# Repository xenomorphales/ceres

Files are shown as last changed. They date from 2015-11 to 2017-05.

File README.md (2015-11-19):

# Cérès

Cérès est le robot secondaire à roues de l'association Xenomorphales. Le but
premier de notre association étant de participer à la coupe de France de
robotique, ce robot respecte les contraintes imposées au robot secondaire, et
notamment, la contrainte de périmètre.

L'ensemble du robot, que ce soit les modèles mécaniques, les schématiques et
les routages électroniques tout comme les codes sources, tout est sous licence
GPLv3. Libre donc à vous tous de donner vie à ce petit robot de vos propres
mains (et gouttes de sueur) et de vous amuser avec ou d'en apprendre plus sur
la robotique. Nous serions ravis que vous nous partagiez vos expériences avec
nos robots.

Vous pouvez retrouver toute notre actualité ou apprendre à nous connaître sur
notre site internet : http://xenomorphales.org/

## Crédits

- [TheFox/GPLv3.md](https://github.com/TheFox/GPLv3.md) (commit c81a2af) :
pour la GPLv3 en Markdown. C'est plus lisible à lire sur GitHub.

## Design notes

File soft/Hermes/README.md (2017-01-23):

# Hermès

Basic Arduino studio code used for the 2016 edition.
It requires the [Teensy 3.0 Hardware Quadrature library](https://forum.pjrc.com/threads/26803-Hardware-Quadrature-Code-for-Teensy-3-x) to function.

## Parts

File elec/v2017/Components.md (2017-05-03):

Component list for v2017 board:
- 20\* Resistor 10kΩ min 0.25W
- 1\* Resistor 18kΩ min 0.25W
- 8\* Resistor 20kΩ min 0.25W
- 1\* Resistor 100kΩ min 0.25W
- 4\* Ceramic capacitor 100nF min 10V
- 1\* Ceramic capacitor 1µF min 10V
- 12\* Ceramic capacitor 10µF min 15V
- 2\* Leaded electrolytic capacitor 470µF min 15V
- 2\* Female XT60 connector
- 1\* Male XT60 connector
- 5\* Male 5264 3P connector
- 2\* Vertical male connector 2.54mm 2 pins (for pull and TTL-Linker RX/TX)
- 5\* Vertical male connector 2.54mm 3 pins (for extra UART and GP2s)
- 4\* Vertical male connector 2.54mm 4 pins (for ultrasonic sensors)
- 2\* Vertical male connector 2.54mm 2x4 pins (for motor driver and gyro)
- 1\* Vertical male connector 2.54mm 2x15 pins (for embedded card)
- 2\* Vertical socket header 2.54mm 6 pins (for the level shifter, unless you want to solder it directly onto the board)

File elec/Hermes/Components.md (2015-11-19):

Component list for Hermes:
- 4\* [Resistor CMS1206 22Ω 0.25W](http://www.mouser.fr/ProductDetail/Vishay-Dale/CRCW120622R0FKEA/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)
- 5\* [Resistor CMS1206 82Ω 0.25W](http://www.mouser.fr/ProductDetail/Vishay-Dale/CRCW120682R0FKEA/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)
- 19\* [Resistor CMS1206 10kΩ 0.25W](http://www.mouser.fr/ProductDetail/Vishay-Dale/CRCW120610K0FKEA/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)
- 5\* [Resistor CMS1206 18kΩ 0.25W](http://www.mouser.fr/ProductDetail/Vishay-Dale/CRCW120618K0FKEA/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)
- 4\* [Resistor CMS1206 20kΩ 0.25W](http://www.mouser.fr/ProductDetail/Vishay-Dale/CRCW120620K0FKEA/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)
- 5\* [Resistor CMS1206 100kΩ 0.25W](http://www.mouser.fr/ProductDetail/Vishay-Dale/CRCW1206100KFKEA/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)
- 2\* [Ceramic capacitor CMS0603 1nF 50V](http://www.mouser.fr/ProductDetail/Taiyo-Yuden/HMK107B7102KA-T/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)
- 4\* [Ceramic capacitor CMS0603 10nF 50V](http://www.mouser.fr/ProductDetail/Taiyo-Yuden/HMK107B7103KA-T/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)
- 8\* [Ceramic capacitor CMS0603 100nF 25V](http://www.mouser.fr/ProductDetail/Taiyo-Yuden/UMK107B7104KA-T/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)
- 5\* [Ceramic capacitor CMS0603 1µF 25V](http://www.mouser.fr/ProductDetail/Taiyo-Yuden/TMK107B7105KA-T/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)
- 6\* [Ceramic capacitor CMS1210 10µF 25V](http://www.mouser.fr/ProductDetail/Taiyo-Yuden/TMK325B7106KN-TR/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)
- 2\* [Leaded electrolytic capacitor 330µF 35V](http://www.mouser.fr/ProductDetail/Nichicon/UVZ1V331MPD/?qs=sGAEpiMZZMtZ1n0r9vR22cbP6Wf%2fHrkhX5OqxJCqtTQ%3d)
- 5\* [Green LED CMS1206](http://www.mouser.fr/ProductDetail/Kingbright/AP3216CGCK/?qs=VdjlWU%2fzoOG1eeDl%2fnjAXA%3d%3d)
- 2\* [Texas Instruments LMD18201](http://www.mouser.fr/Search/ProductDetail.aspx?qs=7lkVKPoqpbYdwidBC23sGA%3d%3d)
- 10\* [Fuse 5mm x 20mm 6A 125V fast-acting](http://www.mouser.fr/ProductDetail/Bussmann-Eaton/BK-GMA-6-R/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) (10 so you have some in advance)
- 1\* [Fuse holder 6.3A 250V](http://www.mouser.fr/ProductDetail/Littelfuse/64600001003/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)
- 7\* [Vertical male connector 2.54mm 2 pins](http://www.mouser.fr/Search/ProductDetail.aspx?qs=hSmm4fxMIuPWb6osY0uomA%3d%3d)
- 7\* [Vertical female connector 2.54mm 2 pins](http://www.mouser.fr/Search/ProductDetail.aspx?qs=mrPiglD9aYKHxZkM06vJ3A%3d%3d)
- 8\* [Vertical male connector 2.54mm 3 pins](http://www.mouser.fr/ProductDetail/Molex/22-27-2031/?qs=sGAEpiMZZMs%252bGHln7q6pm%252bS0pk2Wo0XxndcUoWleoGk%3d)
- 8\* [Vertical female connector 2.54mm 3 pins](http://www.mouser.fr/ProductDetail/Molex/22-01-2035/?qs=%2fha2pyFadujIEQkzoGlzi6OdgxxLl5ZwtIU0IZrEPkY%3d)
- 2\* [Vertical male connector 2.54mm 4 pins](http://www.mouser.fr/ProductDetail/Molex/22-27-2041/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)
- 2\* [Vertical female connector 2.54mm 4 pins](http://www.mouser.fr/Search/ProductDetail.aspx?qs=mrPiglD9aYK6DF%252b0szbDVw%3d%3d)
- 46\* [Female connector contact](http://www.mouser.fr/Search/ProductDetail.aspx?qs=BLN8Q0P37WapYBZgTV5Zeg%3d%3d)
- 2\* [Teensy socket header](http://www.mouser.fr/ProductDetail/3M/929974-01-14-RK/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) (not necessary if you want to solder the Teensy directly on the board)
- 1\* [Teensy 3.1/3.2 with header pins](https://www.pjrc.com/store/teensy32_pins.html)
- 1\* [XT60 connectors pack (5 pairs)](http://www.hobbyking.com/hobbyking/store/__9572__Nylon_XT60_Connectors_Male_Female_5_pairs_GENUINE.html)

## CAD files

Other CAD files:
meca/v2015/axe.ipt
meca/v2015/axe_roue_moteur.ipt
meca/v2015/base.ipt
meca/v2015/encoder_wheel.ipt
meca/v2015/encoder_wheel_support.ipt
meca/v2015/mat.ipt
meca/v2015/motor_support.ipt
meca/v2015/support_batteries.ipt
meca/v2015/support_discovery.ipt
meca/v2015/support_puissance.ipt
meca/v2015/wheel.ipt
meca/v2015/wheel_adapter.ipt
meca/v2016/base.ipt
meca/v2016/battery_base.ipt
meca/v2016/encoder.iam
meca/v2016/encoder_block.iam
meca/v2016/encoder_support.ipt
meca/v2016/gp2_block.iam
meca/v2016/middle_base.ipt
meca/v2016/motor.iam
meca/v2016/odometer_base.ipt
meca/v2016/odometer_block.iam
meca/v2016/robot_base.iam
meca/v2016/rolling_base_board.ipt
meca/v2016/tendeur.ipt
meca/v2016/tendeur_base.ipt
meca/v2016/tendeur_base_low.ipt
meca/v2016/tendeur_base_up.ipt
meca/v2016/tendeur_block.iam
meca/v2016/tendeur_complet.iam
meca/v2016/tendeur_roue.ipt
meca/v2016/top_base.ipt
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

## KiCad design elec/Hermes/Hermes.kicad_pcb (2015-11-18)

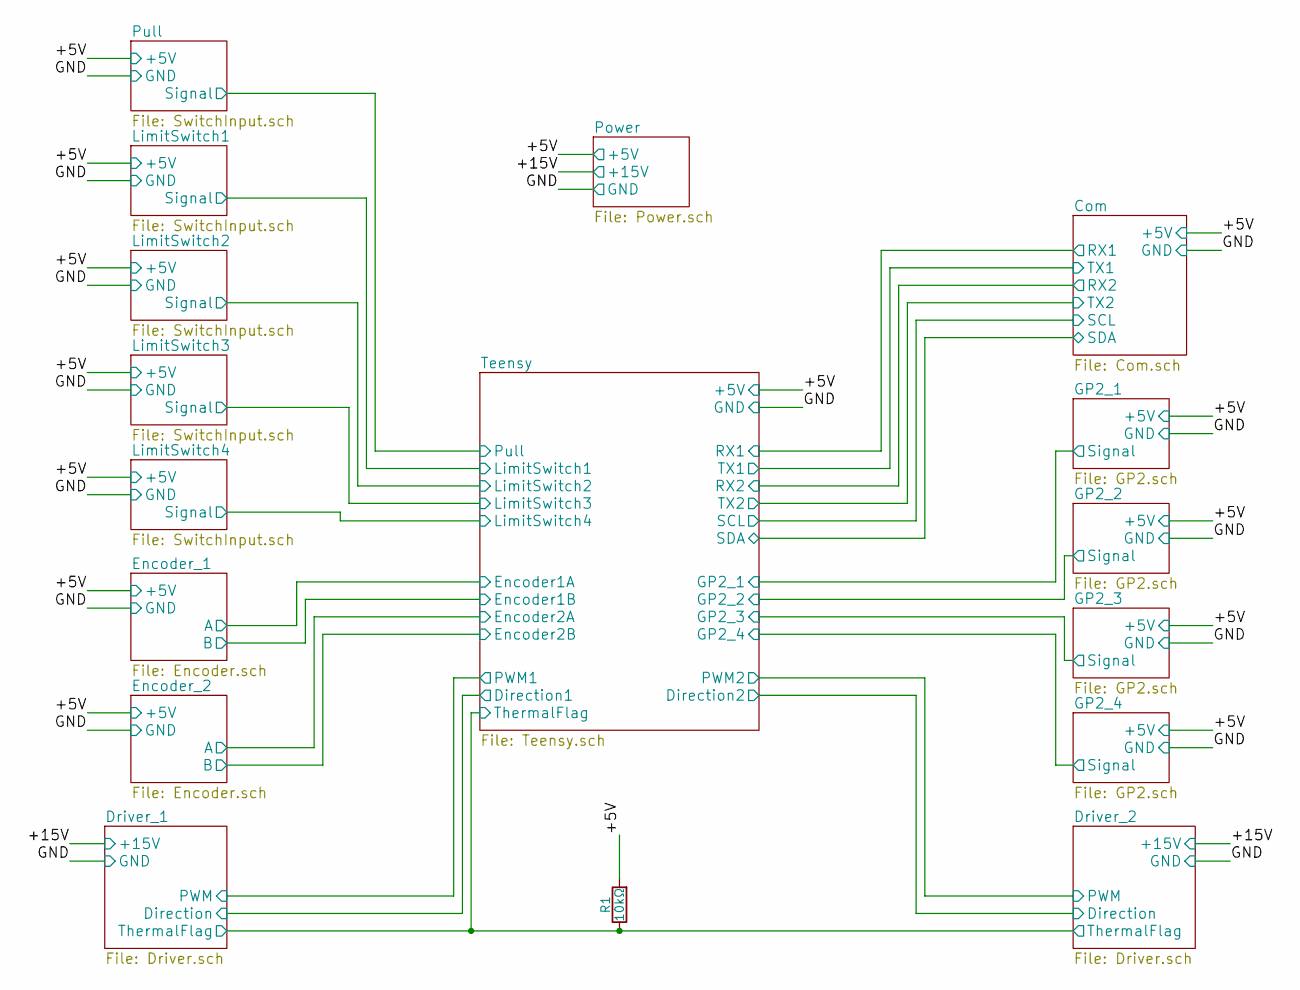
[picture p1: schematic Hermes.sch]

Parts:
R1: 10kΩ; R_CMS1206

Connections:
/Com/+5V: R1.2; also elsewhere on the board
/Driver_1/ThermalFlag: R1.1; also elsewhere on the board

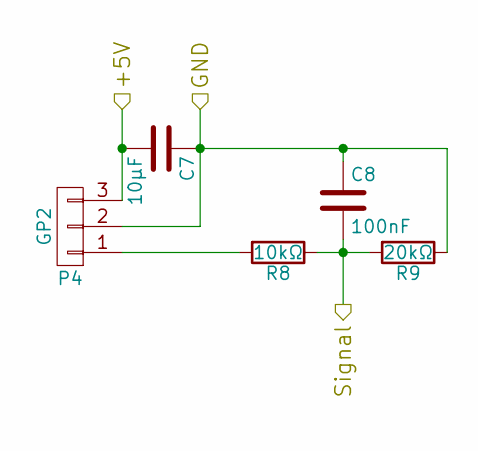
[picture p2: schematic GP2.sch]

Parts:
C1: 10µF; C_CMS1210
C2: 100nF; C_CMS0603
P1: GP2; Conn_01x03
R2: 10kΩ; R_CMS1206
R3: 20kΩ; R_CMS1206

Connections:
/Com/+5V: C1.2, P1.3; also elsewhere on the board
/Com/GND: C1.1, C2.1, P1.2, R3.1; also elsewhere on the board
/Teensy/GP2_1: C2.2, R2.1, R3.2; also elsewhere on the board
unnamed: P1.1, R2.2

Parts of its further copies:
C3, C5, C7: 10µF; C_CMS1210
C4, C6, C8: 100nF; C_CMS0603
P2, P3, P4: GP2; Conn_01x03
R4, R6, R8: 10kΩ; R_CMS1206
R5, R7, R9: 20kΩ; R_CMS1206

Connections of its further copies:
/Com/+5V: C3.2, C5.2, C7.2, P2.3, P3.3, P4.3; also elsewhere on the board
/Com/GND: C3.1, C4.1, C5.1, C6.1, C7.1, C8.1, P2.2, P3.2, P4.2, R5.1, R7.1, R9.1; also elsewhere on the board
/Teensy/GP2_2: C4.2, R4.1, R5.2; also elsewhere on the board
/Teensy/GP2_3: C6.2, R6.1, R7.2; also elsewhere on the board
/Teensy/GP2_4: C8.2, R8.1, R9.2; also elsewhere on the board
unnamed: P2.1, R4.2
unnamed: P3.1, R6.2
unnamed: P4.1, R8.2

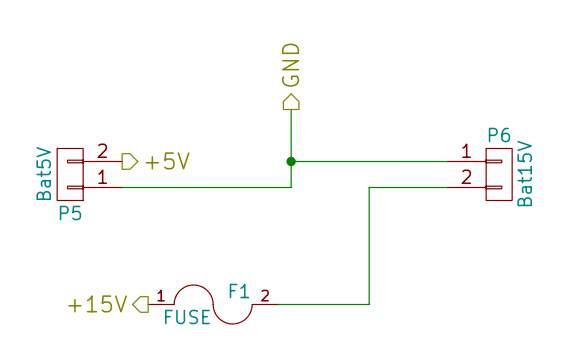
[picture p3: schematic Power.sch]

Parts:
F1: FUSE; Fuse
P5: Bat5V; Conn_01x02
P6: Bat15V; Power_Conn_01x02

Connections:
/Com/+5V: P5.2; also elsewhere on the board
/Com/GND: P5.1, P6.1; also elsewhere on the board
/Driver_1/+15V: F1.1; also elsewhere on the board
unnamed: F1.2, P6.2

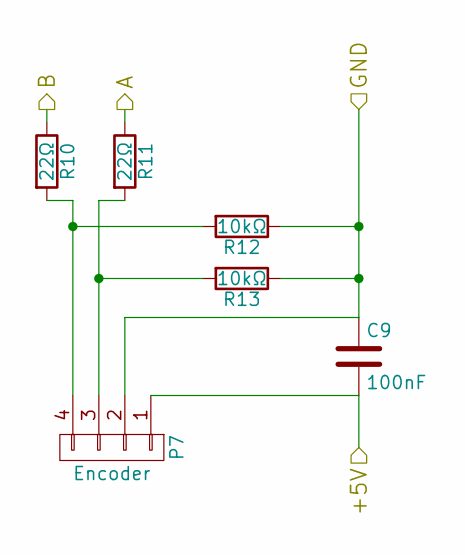
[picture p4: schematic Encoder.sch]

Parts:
C9: 100nF; C_CMS0603
P7: Encoder; Conn_01x04
R10, R11: 22Ω; R_CMS1206
R12, R13: 10kΩ; R_CMS1206

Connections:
/Com/+5V: C9.2, P7.1; also elsewhere on the board
/Com/GND: C9.1, P7.2, R12.1, R13.1; also elsewhere on the board
/Encoder_1/A: R11.1; also elsewhere on the board
/Encoder_1/B: R10.1; also elsewhere on the board
unnamed: P7.3, R11.2, R13.2
unnamed: P7.4, R10.2, R12.2

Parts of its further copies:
C10: 100nF; C_CMS0603
P8: Encoder; Conn_01x04
R14, R15: 22Ω; R_CMS1206
R16, R17: 10kΩ; R_CMS1206

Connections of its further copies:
/Com/+5V: C10.2, P8.1; also elsewhere on the board
/Com/GND: C10.1, P8.2, R16.1, R17.1; also elsewhere on the board
/Encoder_2/A: R15.1; also elsewhere on the board
/Encoder_2/B: R14.1; also elsewhere on the board
unnamed: P8.3, R15.2, R17.2
unnamed: P8.4, R14.2, R16.2

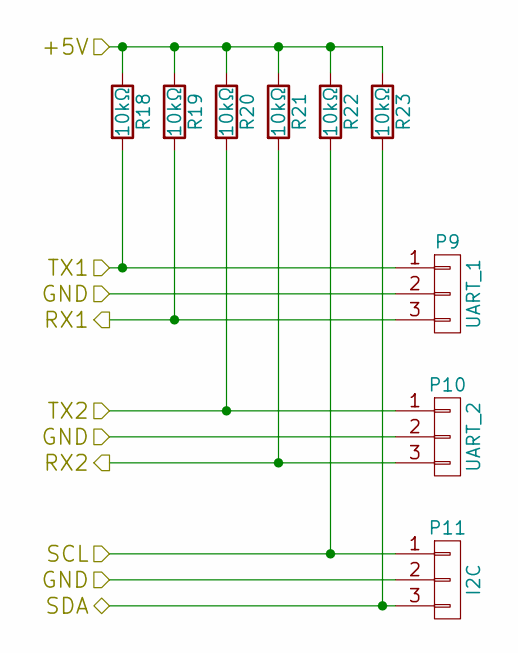
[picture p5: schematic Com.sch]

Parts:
P9: UART_1; Conn_01x03
P10: UART_2; Conn_01x03
P11: I2C; Conn_01x03
R18, R19, R20, R21, R22, R23: 10kΩ; R_CMS1206

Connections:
/Com/+5V: R18.1, R19.1, R20.1, R21.1, R22.1, R23.1; also elsewhere on the board
/Com/GND: P9.2, P10.2, P11.2; also elsewhere on the board
/Com/RX1: P9.3, R19.2; also elsewhere on the board
/Com/RX2: P10.3, R21.2; also elsewhere on the board
/Com/SCL: P11.1, R22.2; also elsewhere on the board
/Com/SDA: P11.3, R23.2; also elsewhere on the board
/Com/TX1: P9.1, R18.2; also elsewhere on the board
/Com/TX2: P10.1, R20.2; also elsewhere on the board

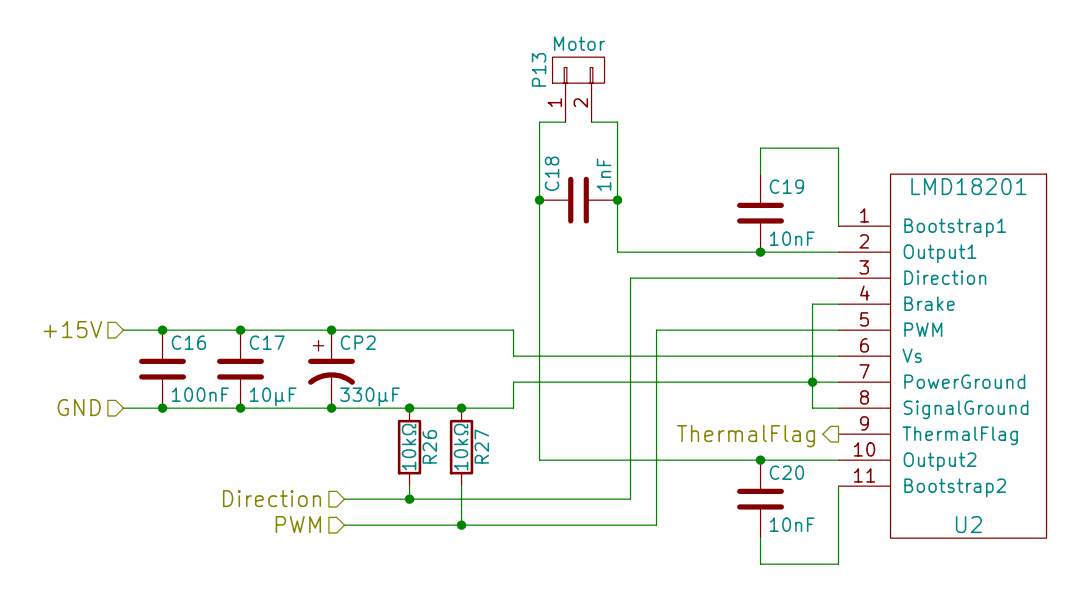
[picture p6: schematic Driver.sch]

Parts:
C11: 100nF; C_CMS0603
C12: 10µF; C_CMS1210
C13: 1nF; C_CMS0603
C14, C15: 10nF; C_CMS0603
CP1: 330µF; C_Radial
P12: Motor; Power_Conn_01x02
R24, R25: 10kΩ; R_CMS1206
U1: LMD18201

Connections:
/Com/GND: C11.2, C12.2, CP1.2, R24.1, R25.1, U1.4 (Brake), U1.7 (PowerGround), U1.8 (SignalGround); also elsewhere on the board
/Driver_1/+15V: C11.1, C12.1, CP1.1, U1.6 (Vs); also elsewhere on the board
/Driver_1/Direction: R24.2, U1.3 (Direction); also elsewhere on the board
/Driver_1/PWM: R25.2, U1.5 (PWM); also elsewhere on the board
/Driver_1/ThermalFlag: U1.9 (ThermalFlag); also elsewhere on the board
unnamed: C13.1, C15.1, P12.1, U1.10 (Output2)
unnamed: C13.2, C14.2, P12.2, U1.2 (Output1)
unnamed: C14.1, U1.1 (Bootstrap1)
unnamed: C15.2, U1.11 (Bootstrap2)

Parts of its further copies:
C16: 100nF; C_CMS0603
C17: 10µF; C_CMS1210
C18: 1nF; C_CMS0603
C19, C20: 10nF; C_CMS0603
CP2: 330µF; C_Radial
P13: Motor; Power_Conn_01x02
R26, R27: 10kΩ; R_CMS1206
U2: LMD18201

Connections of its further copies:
/Com/GND: C16.2, C17.2, CP2.2, R26.1, R27.1, U2.4 (Brake), U2.7 (PowerGround), U2.8 (SignalGround); also elsewhere on the board
/Driver_1/+15V: C16.1, C17.1, CP2.1, U2.6 (Vs); also elsewhere on the board
/Driver_1/ThermalFlag: U2.9 (ThermalFlag); also elsewhere on the board
/Driver_2/Direction: R26.2, U2.3 (Direction); also elsewhere on the board
/Driver_2/PWM: R27.2, U2.5 (PWM); also elsewhere on the board
unnamed: C18.1, C20.1, P13.1, U2.10 (Output2)
unnamed: C18.2, C19.2, P13.2, U2.2 (Output1)
unnamed: C19.1, U2.1 (Bootstrap1)
unnamed: C20.2, U2.11 (Bootstrap2)

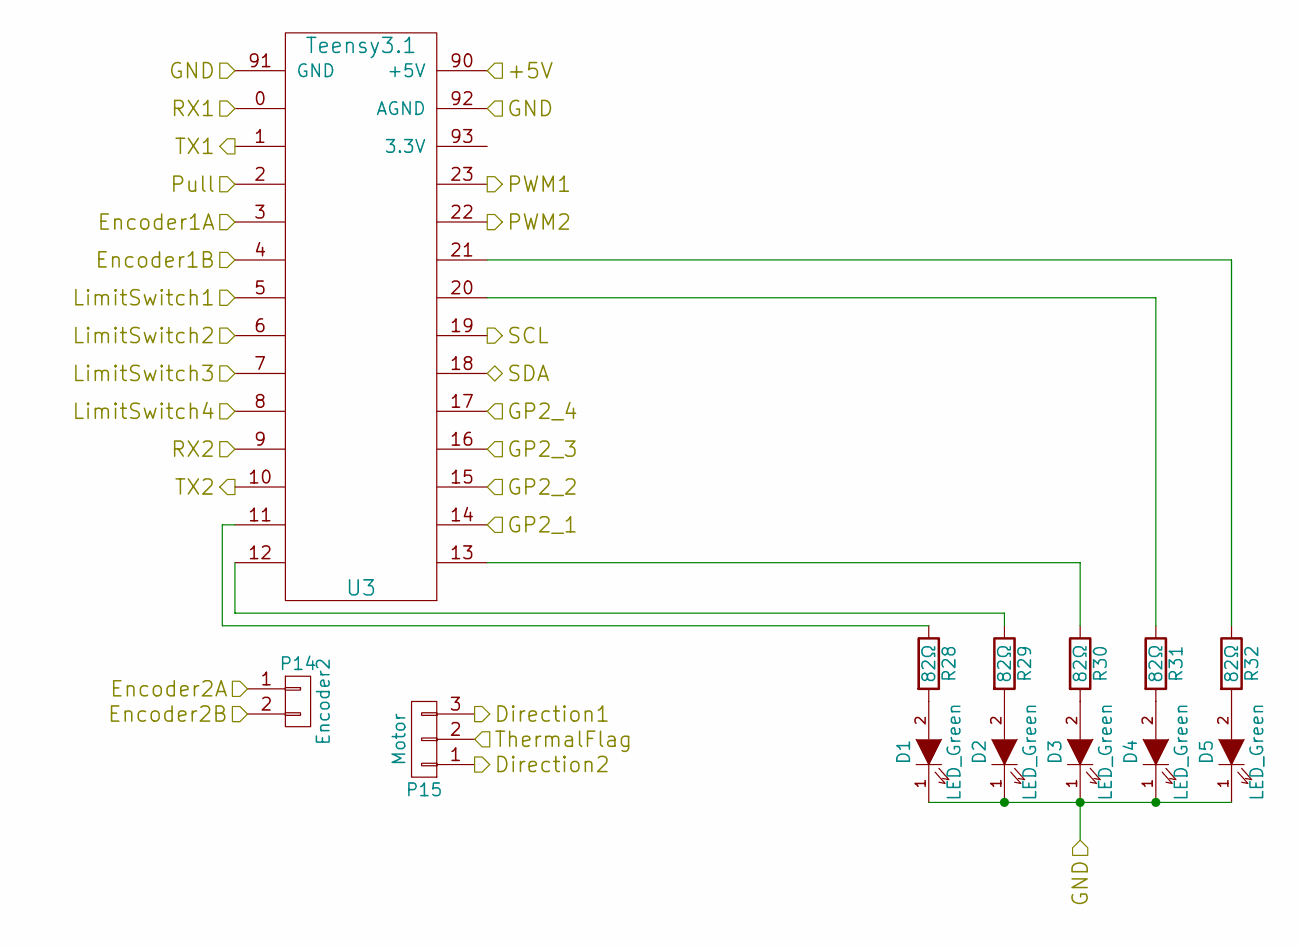
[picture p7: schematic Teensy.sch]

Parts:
D1, D2, D3, D4, D5: LED_Green; LED_Green_CMS
P14: Encoder2; Conn_01x02
P15: Motor; Conn_01x03
R28, R29, R30, R31, R32: 82Ω; R_CMS1206
U3: Teensy3.1

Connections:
/Com/+5V: U3.90 (+5V); also elsewhere on the board
/Com/GND: D1.1 (K), D2.1 (K), D3.1 (K), D4.1 (K), D5.1 (K), U3.91 (GND), U3.92 (AGND); also elsewhere on the board
/Com/RX1: U3.0; also elsewhere on the board
/Com/RX2: U3.9; also elsewhere on the board
/Com/SCL: U3.19; also elsewhere on the board
/Com/SDA: U3.18; also elsewhere on the board
/Com/TX1: U3.1; also elsewhere on the board
/Com/TX2: U3.10; also elsewhere on the board
/Driver_1/Direction: P15.3; also elsewhere on the board
/Driver_1/PWM: U3.23; also elsewhere on the board
/Driver_1/ThermalFlag: P15.2; also elsewhere on the board
/Driver_2/Direction: P15.1; also elsewhere on the board
/Driver_2/PWM: U3.22; also elsewhere on the board
/Encoder_1/A: U3.3; also elsewhere on the board
/Encoder_1/B: U3.4; also elsewhere on the board
/Encoder_2/A: P14.1; also elsewhere on the board
/Encoder_2/B: P14.2; also elsewhere on the board
/Teensy/GP2_1: U3.14; also elsewhere on the board
/Teensy/GP2_2: U3.15; also elsewhere on the board
/Teensy/GP2_3: U3.16; also elsewhere on the board
/Teensy/GP2_4: U3.17; also elsewhere on the board
/Teensy/LimitSwitch1: U3.5; also elsewhere on the board
/Teensy/LimitSwitch2: U3.6; also elsewhere on the board
/Teensy/LimitSwitch3: U3.7; also elsewhere on the board
/Teensy/LimitSwitch4: U3.8; also elsewhere on the board
/Teensy/Pull: U3.2; also elsewhere on the board
unnamed: D1.2 (A), R28.2
unnamed: D2.2 (A), R29.2
unnamed: D3.2 (A), R30.2
unnamed: D4.2 (A), R31.2
unnamed: D5.2 (A), R32.2
unnamed: R28.1, U3.11
unnamed: R29.1, U3.12
unnamed: R30.1, U3.13
unnamed: R31.1, U3.20
unnamed: R32.1, U3.21

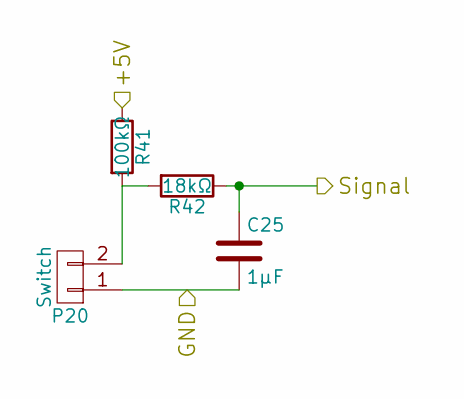
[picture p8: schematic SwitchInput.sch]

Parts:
C21: 1µF; C_CMS0603
P16: Switch; Conn_01x02
R33: 100kΩ; R_CMS1206
R34: 18kΩ; R_CMS1206

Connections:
/Com/+5V: R33.1; also elsewhere on the board
/Com/GND: C21.2, P16.1; also elsewhere on the board
/Teensy/Pull: C21.1, R34.1; also elsewhere on the board
unnamed: P16.2, R33.2, R34.2

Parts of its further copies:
C22, C23, C24, C25: 1µF; C_CMS0603
P17, P18, P19, P20: Switch; Conn_01x02
R35, R37, R39, R41: 100kΩ; R_CMS1206
R36, R38, R40, R42: 18kΩ; R_CMS1206

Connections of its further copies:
/Com/+5V: R35.1, R37.1, R39.1, R41.1; also elsewhere on the board
/Com/GND: C22.2, C23.2, C24.2, C25.2, P17.1, P18.1, P19.1, P20.1; also elsewhere on the board
/Teensy/LimitSwitch1: C22.1, R36.1; also elsewhere on the board
/Teensy/LimitSwitch2: C23.1, R38.1; also elsewhere on the board
/Teensy/LimitSwitch3: C24.1, R40.1; also elsewhere on the board
/Teensy/LimitSwitch4: C25.1, R42.1; also elsewhere on the board
unnamed: P17.2, R35.2, R36.2
unnamed: P18.2, R37.2, R38.2
unnamed: P19.2, R39.2, R40.2
unnamed: P20.2, R41.2, R42.2

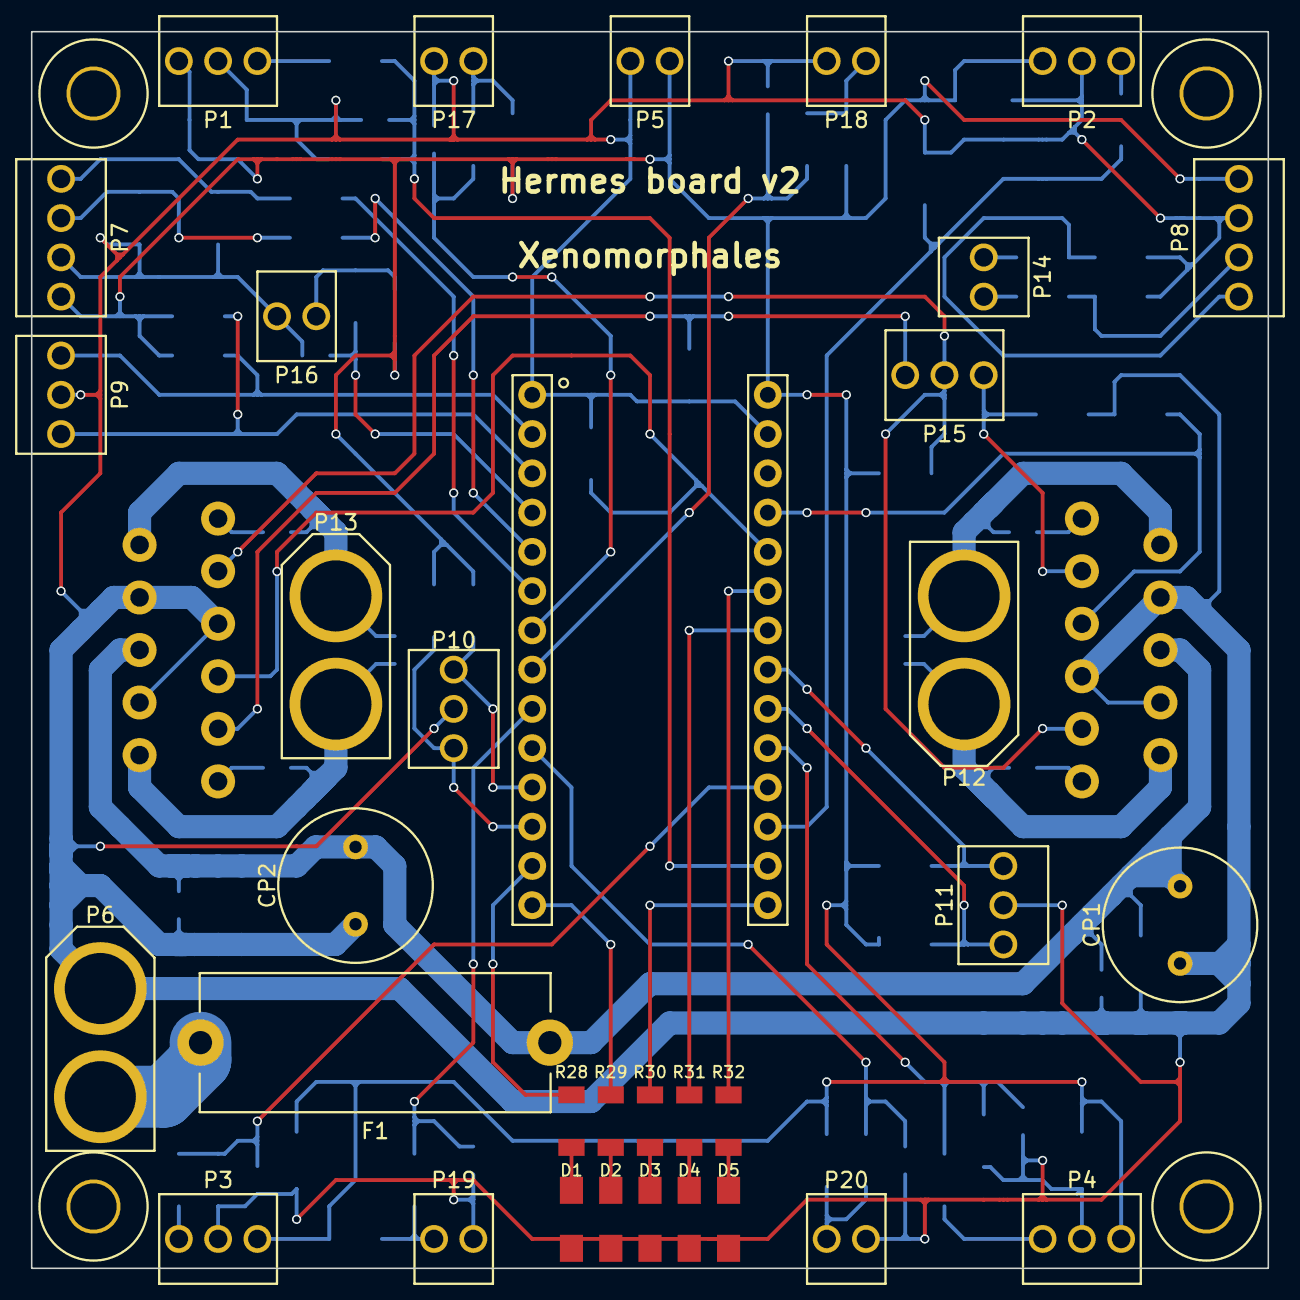
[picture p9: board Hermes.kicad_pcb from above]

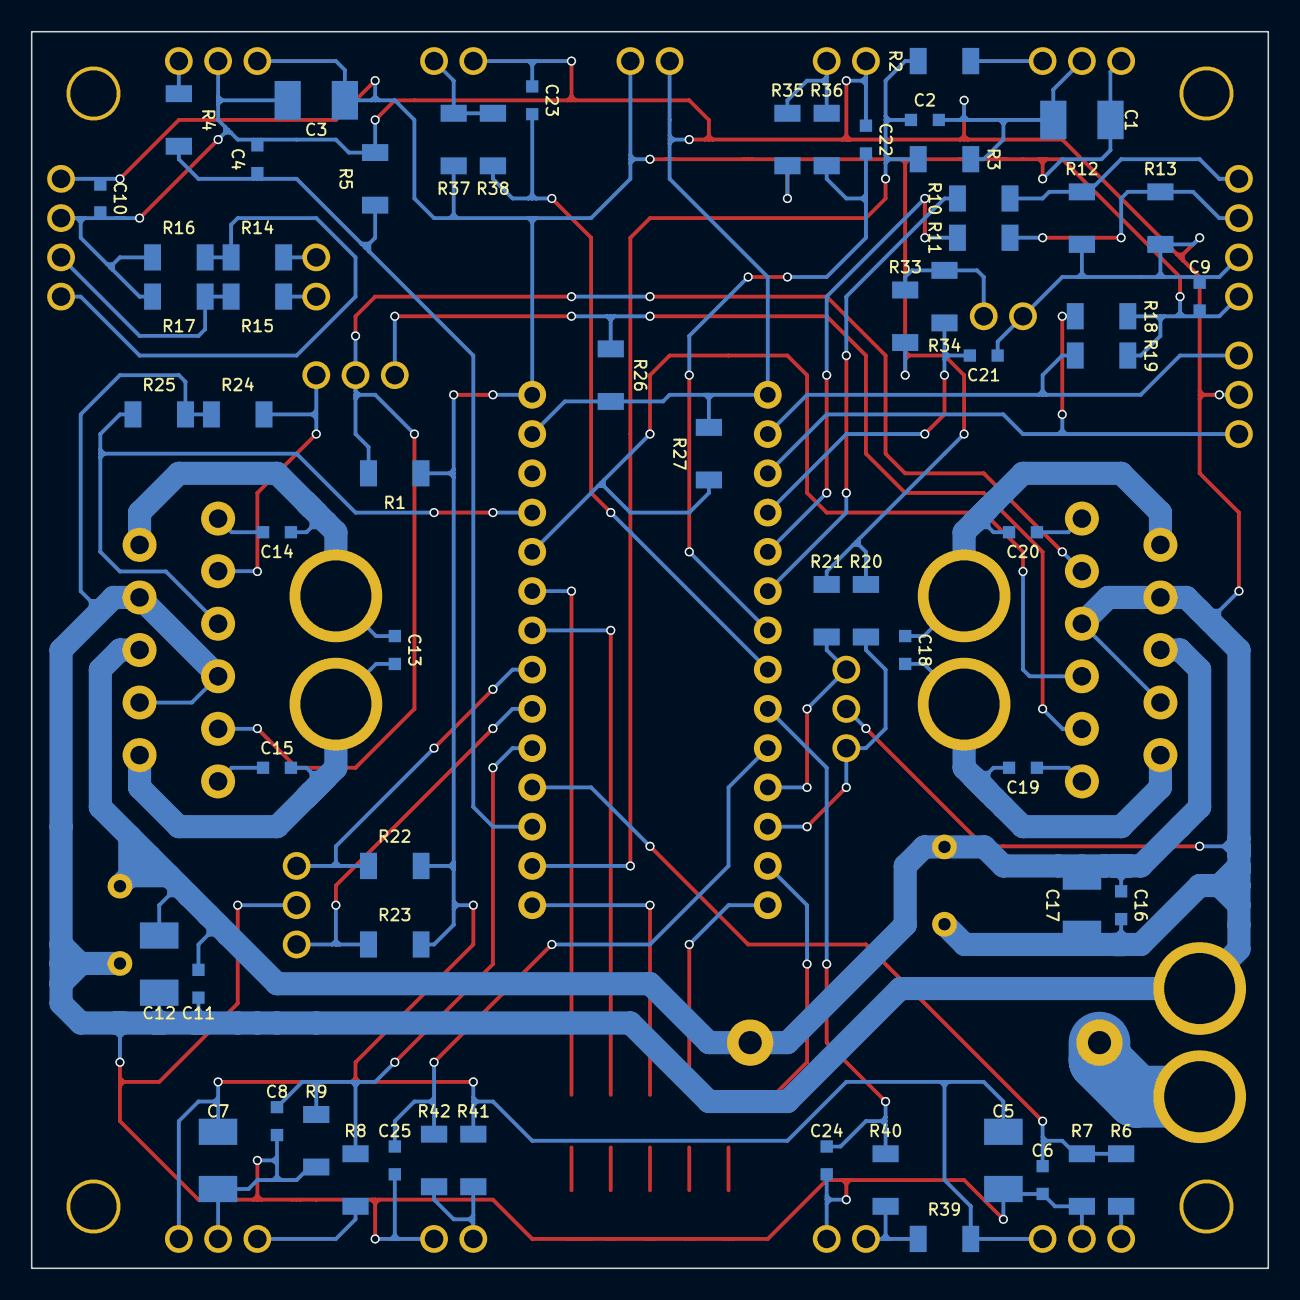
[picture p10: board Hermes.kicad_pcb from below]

Board: 2 copper layers, 80.0 x 80.0 mm, 98 parts (62 on the bottom side), 59 nets.

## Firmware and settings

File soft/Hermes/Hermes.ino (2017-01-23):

#include "QuadDecode_def.h"

#define NB_LEDS 5
const int leds[] = { 11, 12, 13, 20, 21 };

#define NB_BUTTONS 4
const int buttons[] = { 5, 6, 7 , 8 };

const int startPull = 2;

#define NB_GP2S 4
const int gp2s[] = { 0, 1, 2, 3 };
#define GP2_BLOCK_AT   1000 /*432*/ /*288*/
#define GP2_UNBLOCK_AT 1000 /*324*/ /*216*/

#define NB_MOTORS 2
const int motorPWMs[] = { 22, 23 };
const int motorDirs[] = { 26, 31 };

QuadDecode<1> encoder1;  // Template using FTM1
QuadDecode<2> encoder2;  // Template using FTM2

#define SPEED 125

void display(int n) {
  for(int i = 0; i <= NB_LEDS; ++i)
    digitalWrite(leds[i], ((1<<i) & n) ? HIGH : LOW);
}

static long long lastE[2] = { 0, 0 };
static long long curE[2] = { 0, 0 };

void updateEnc() {
  lastE[0] = curE[0];
  lastE[1] = curE[1];

  curE[0] = -encoder2.calcPosn();
  curE[1] = encoder1.calcPosn();
}

static long long lastErr[2] = { 0, 0 };
static float pidSpeeds[2][3] = {
  //    P     I     D
  {   0.5,   0.,  0.5 }, // Droit
  {   0.5,   0.,  0.5 }, // Gauche
};

void updateMotor(int m, int speed) {
  long long actualSpeed = curE[m] - lastE[m];
  long long err = speed - actualSpeed;
  
  long long P = pidSpeeds[m][0] * err;
  long long I = 0;
  long long D = pidSpeeds[m][2] * (err - lastErr[m]);

  long long cmd = P + I + D;

  if(m == 0) cmd = -cmd;
  
  analogWrite(motorPWMs[m], (abs(cmd) > 255) ? 255 : abs(cmd));
  digitalWrite(motorDirs[m], (cmd >= 0) ? HIGH : LOW);
  
  lastErr[m] = err;
}

long long lastErrAngle = 0;
static float pidAngle[3] = {
  //    P     I     D
      0.5,   0.,  0.5,
};

long long lastDistance = 0;
long long lastErrSpeed = 0;
static float pidSpeed[3] = {
  //    P     I     D
      0.5,   0.,  0.5,
};

void updateAngleSpeed(int angle, int speed) {
  long long actualAngle = (curE[1] - curE[0]) / 2;
  long long actualDistance = (curE[1] + curE[0]) / 2;

  long long errAngle = angle - actualAngle;

  long long PAngle = pidAngle[0] * errAngle;
  long long IAngle = 0;
  long long DAngle = pidAngle[2] * (errAngle - lastErrAngle);

  long long actualSpeed = lastDistance - actualDistance;

  long long errSpeed = speed - actualSpeed;

  long long PSpeed = pidSpeed[0] * errSpeed;
  long long ISpeed = 0;
  long long DSpeed = pidSpeed[2] * (errSpeed - lastErrSpeed);

  updateMotor(1, PSpeed + ISpeed + DSpeed + PAngle + IAngle + DAngle);
  updateMotor(0, PSpeed + ISpeed + DSpeed - PAngle - IAngle - DAngle);

  lastErrAngle = errAngle;
  lastDistance = actualDistance;
  lastErrSpeed = errSpeed;
}

void updateMotors(int speed) {
  updateMotor(0, speed);
  updateMotor(1, speed);
}

void setup() {
  // put your setup code here, to run once:
  delay(1000);

  for(int i = 0; i < NB_LEDS; ++i)
    pinMode(leds[i], OUTPUT);

  display(0x1F);

  for(int i = 0; i < NB_BUTTONS; ++i)
    pinMode(buttons[i], INPUT);

  pinMode(startPull, INPUT);

  for(int i = 0; i < NB_GP2S; ++i)
    pinMode(gp2s[i], INPUT);

  for(int i = 0; i < NB_MOTORS; ++i) {
    pinMode(motorPWMs[i], OUTPUT);
    pinMode(motorDirs[i], OUTPUT);
  }

  updateMotors(0);

  encoder1.setup();
  encoder2.setup();

  delay(1000);
}

void loop() {
  // put your main code here, to run repeatedly:
  static int time = 0;
  static int step = 0;
  
  display(step);

  if(time >= 85000) {
    display(0x1F);
    while(1) {
      analogWrite(motorPWMs[0], 0);
      analogWrite(motorPWMs[1], 0);
    }
  }

  if(step == 0) {
    while(digitalRead(buttons[0]) == HIGH);
    step = 1;
  }
  else if(step == 1) {
    //while(digitalRead(buttons[1]) == HIGH);
    while(digitalRead(startPull) == LOW);
    time = 0;
    step = 2;
    encoder1.start();
    encoder2.start();
  }
  else if(step == 2) {
    int speed = SPEED;
    long long dist;
    static bool lastBlocked = false;
    int gp2Sum = 0;
    
    updateEnc();
    dist = curE[0] + curE[1];

    for(int i = 0; i < 2 && speed != 0; ++i)
      if(lastBlocked) {
        if(analogRead(gp2s[i]) <= GP2_UNBLOCK_AT)
          ++gp2Sum;
      }
      else {
        if(analogRead(gp2s[i]) >= GP2_BLOCK_AT)
          ++gp2Sum;
      }

    if(lastBlocked && gp2Sum < 2)
      speed = 0;
    else if(lastBlocked && gp2Sum == 2)
      lastBlocked = false;
    else if(!lastBlocked && gp2Sum > 0) {
      lastBlocked = true;
      speed = 0;
    }

    display(step | ((lastBlocked) ? 0b11000 : 0));
    
    //updateMotors(speed);
    updateAngleSpeed(0, speed);

    if(dist >= 1024*34)
      step = 3;
  }
  else if(step == 3) {
    updateEnc();
    updateMotors(0);
    if(time >= 80000)
      step = 4;
  }
  /*else if(step == 4) {
    // Toupie
    updateEnc();
    updateMotor(0, SPEED);
    updateMotor(1, -SPEED);
  }*/
  else {
    updateEnc();
    updateMotors(0);
  }
  
  delay(10);
  time += 10;
}

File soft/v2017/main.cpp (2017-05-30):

#include <stdio.h>
#include <math.h>
#include <string.h>

#include <shell.h>

#include "task.h"

#include "strategy.hpp"

extern int cmd_read(int argc, char** argv);
extern int cmd_write(int argc, char** argv);
extern int cmd_ls(int argc, char** argv);

extern int cmd_service(int argc, char** argv);

extern int cmd_feetech(int argc, char **argv);
extern int cmd_dxl(int argc, char **argv);

extern int cmd_test_all(int, char**);
extern int cmd_test_speed(int argc, char** argv);
extern int cmd_test_funny(int argc, char** argv);
extern int cmd_test_grip(int argc, char** argv);
extern int cmd_test_arm(int argc, char** argv);
extern int cmd_test_side(int argc, char** argv);

static const shell_command_t shell_commands[] = {
  { "read", "", cmd_read },
  { "write", "", cmd_write },
  { "ls", "", cmd_ls },

  { "service", "Service management", cmd_service },

  { "feetech", "Feetech management", cmd_feetech },
  { "dxl", "Dynamixel management", cmd_dxl },

  { "init_all", "Init all services", cmd_test_all},
  { "test", "Test speed*time", cmd_test_speed},
  { "funny", "Test funny action", cmd_test_funny},
  { "grip", "Test grip", cmd_test_grip},
  { "arm", "Test grip", cmd_test_arm},
  { "side", "Choose side", cmd_test_side},

  { NULL, NULL, NULL }
};

int main(void) {
  task_init();

  puts("Starting the shell");

  Strategy::instance().start();
  char line_buf[SHELL_DEFAULT_BUFSIZE];
  shell_run(shell_commands, line_buf, SHELL_DEFAULT_BUFSIZE);

  return 0;
}

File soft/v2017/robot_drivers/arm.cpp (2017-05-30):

#include "arm.hpp"

#include "servo.hpp"

#include <thread.h>
#include <xtimer.h>

#include <stdint.h>

#define ARM_SERVO_NUMOF (5)

#define SERVO_DELTA (10)

typedef enum {
  RETRACTED       = 0,
  DEPLOYED_MIDDLE = 1,
  DEPLOYED_DOWN   = 2,
} pose_t;

typedef enum {
  STATE_OFF,
  STATE_INIT,
  STATE_RETRACTED,
  STATE_DEPLOYED,
  STATE_MOVING_RETRACT_1,
  STATE_MOVING_RETRACT_2,
  STATE_MOVING_DEPLOY_1,
  STATE_MOVING_DEPLOY_2,

  STATE_ERROR
} state_t;

typedef enum {
  EVENT_INIT,
  EVENT_DEPLOY,
  EVENT_RETRACT,
  EVENT_DONE,

  EVENT_EMPTY
} event_t;

static uint8_t _left_ids[ARM_SERVO_NUMOF] = {
  10, 11, 12, 13, 14
};

static uint8_t _right_ids[ARM_SERVO_NUMOF] = {
  20, 21, 22, 23, 24
};

static uint16_t _left_poses[3][ARM_SERVO_NUMOF] = {
  {170,  80, 540, 400, 200}, // RETRACTED
  {512, 512, 630, 270, 130}, // DEPLOYED_MIDDLE
  {512, 512, 100, 700, 130}, // DEPLOYED_DOWN
};

static uint16_t _right_poses[3][ARM_SERVO_NUMOF] = {
  {140, 140, 540, 330, 180}, // RETRACTED
  {512, 512, 630, 270, 150}, // DEPLOYED_MIDDLE
  {512, 512, 100, 700, 150}, // DEPLOYED_DOWN
};

static float _left_angles[ARM_SERVO_NUMOF] = { 0,0,0,0,0 };
static float _right_angles[ARM_SERVO_NUMOF] = { 0,0,0,0,0 };

static float _no_angles[ARM_SERVO_NUMOF] = { 0,0,0,0,0 };

static state_t _left_state = STATE_OFF;
static event_t _left_event = EVENT_EMPTY;

static state_t _right_state = STATE_OFF;
static event_t _right_event = EVENT_EMPTY;

static char arm_thread_stack[THREAD_STACKSIZE_MAIN];

void _servo_enable(uint8_t id) {
  feetech_t dev;
  feetech_init(&dev, &ServoBus::instance().stream(), id);
  feetech_write8(&dev, SCS15_TORQUE_ENABLE, 1);
  feetech_write16(&dev, SCS15_GOAL_TIME, 512);
}

void _servo_set_angle(uint8_t id, uint16_t angle) {
  feetech_t dev;
  feetech_init(&dev, &ServoBus::instance().stream(), id);
  feetech_write8(&dev, SCS15_TORQUE_ENABLE, 1);
  feetech_write16(&dev, SCS15_GOAL_TIME, 512);
  feetech_write16(&dev, SCS15_GOAL_POSITION, angle);
}

bool _servo_check_angle(uint8_t id, uint16_t angle) {
  uint16_t res = 0xFFFF;
  feetech_t dev;
  feetech_init(&dev, &ServoBus::instance().stream(), id);
  feetech_read16(&dev, SCS15_PRESENT_POSITION, &res);

  return abs((int)res-(int)angle) < SERVO_DELTA;
}

void _arm_enable(uint8_t ids[ARM_SERVO_NUMOF]) {
  for(size_t i = 0 ; i < ARM_SERVO_NUMOF ; i++) {
    _servo_enable(ids[i]);
  }
}

uint16_t add_angle(uint16_t pose, float angle) {
  const int p = pose;
  const int a = angle * 1024 / 3.1415;

  const int ret = p+a;

  if(ret < 0) return 0;
  if(ret > 1024) return 1024;

  return ret;
}

void _arm_set_pose(uint8_t ids[ARM_SERVO_NUMOF], uint16_t pose[ARM_SERVO_NUMOF], float angle[ARM_SERVO_NUMOF]) {
  for(size_t i = 0 ; i < ARM_SERVO_NUMOF ; i++) {
    _servo_set_angle(ids[i], add_angle(pose[i], angle[i]));
  }
}

bool _arm_check_pose(uint8_t ids[ARM_SERVO_NUMOF], uint16_t pose[ARM_SERVO_NUMOF], float angle[ARM_SERVO_NUMOF]) {
  for(size_t i = 0 ; i < ARM_SERVO_NUMOF ; i++) {
    if(!_servo_check_angle(ids[i], add_angle(pose[i], angle[i]))) {
      return false;
    }
  }
  return true;
}

static inline event_t _update_event(uint8_t ids[ARM_SERVO_NUMOF], uint16_t poses[3][ARM_SERVO_NUMOF], float angle[ARM_SERVO_NUMOF], state_t state) {
  if(state == STATE_OFF) {
  }
  else if(state == STATE_INIT) {
    return EVENT_DONE;
  }
  else if(state == STATE_MOVING_DEPLOY_1) {
    if(_arm_check_pose(ids, poses[DEPLOYED_MIDDLE], _no_angles)) {
      return EVENT_DONE;
    }
  }
  else if(state == STATE_MOVING_DEPLOY_2) {
    if(_arm_check_pose(ids, poses[DEPLOYED_DOWN], angle)) {
      return EVENT_DONE;
    }
  }
  else if(state == STATE_MOVING_RETRACT_1) {
    if(_arm_check_pose(ids, poses[DEPLOYED_MIDDLE], _no_angles)) {
      return EVENT_DONE;
    }
  }
  else if(state == STATE_MOVING_RETRACT_2) {
    if(_arm_check_pose(ids, poses[RETRACTED], _no_angles)) {
      return EVENT_DONE;
    }
  }

  return EVENT_EMPTY;
}

static inline state_t _update_state(uint8_t ids[ARM_SERVO_NUMOF], uint16_t poses[3][ARM_SERVO_NUMOF], float angle[ARM_SERVO_NUMOF], state_t state, event_t event) {
  if(state == STATE_OFF) {
    if(event == EVENT_INIT) {
      _arm_enable(ids);
      return STATE_INIT;
    }
  }
  else if(state == STATE_INIT) {
    if(event == EVENT_DONE) {
      _arm_set_pose(ids, poses[DEPLOYED_MIDDLE], _no_angles);
      return STATE_MOVING_RETRACT_1;
    }
  }
  else if(state == STATE_RETRACTED) {
    if(event == EVENT_DEPLOY) {
      _arm_set_pose(ids, poses[DEPLOYED_MIDDLE], _no_angles);
      return STATE_MOVING_DEPLOY_1;
    }
  }
  else if(state == STATE_DEPLOYED) {
    if(event == EVENT_RETRACT) {
      _arm_set_pose(ids, poses[DEPLOYED_MIDDLE], _no_angles);
      return STATE_MOVING_RETRACT_1;
    }
    if(event == EVENT_DEPLOY) {
      _arm_set_pose(ids, poses[DEPLOYED_DOWN], angle);
      return STATE_DEPLOYED;
    }
  }
  else if(state == STATE_MOVING_DEPLOY_1) {
    if(event == EVENT_DONE) {
      _arm_set_pose(ids, poses[DEPLOYED_DOWN], angle);
      return STATE_MOVING_DEPLOY_2;
    }
  }
  else if(state == STATE_MOVING_DEPLOY_2) {
    if(event == EVENT_DONE) {
      return STATE_DEPLOYED;
    }
  }
  else if(state == STATE_MOVING_RETRACT_1) {
    if(event == EVENT_DONE) {
      _arm_set_pose(ids, poses[RETRACTED], _no_angles);
      return STATE_MOVING_RETRACT_2;
    }
  }
  else if(state == STATE_MOVING_RETRACT_2) {
    if(event == EVENT_DONE) {
      return STATE_RETRACTED;
    }
  }

  return state;
}

static inline Arm::ArmState _arm_state(state_t state) {
  switch(state) {
    case STATE_DEPLOYED:
      return Arm::ARM_DEPLOYED;
    case STATE_RETRACTED:
      return Arm::ARM_RETRACTED;
    case STATE_INIT:
    case STATE_MOVING_DEPLOY_1:
    case STATE_MOVING_DEPLOY_2:
    case STATE_MOVING_RETRACT_1:
    case STATE_MOVING_RETRACT_2:
      return Arm::ARM_MOVING;
    case STATE_OFF:
      return Arm::ARM_DISABLED;
    default:
      return Arm::ARM_ERROR;
  }
  return Arm::ARM_ERROR;
}

static void* _arm_update_thread(void* arg) {
  (void) arg;
  xtimer_ticks32_t last_wakeup = xtimer_now();

  while(1) {
    xtimer_periodic_wakeup(&last_wakeup, 1000000UL/10UL);

    if(Arm::instance().state() == Service::RUN) {
      // LEFT
      if(_left_event == EVENT_EMPTY) {
        _left_event = _update_event(_left_ids, _left_poses, _left_angles, _left_state);
      }

      _left_state = _update_state(_left_ids, _left_poses, _left_angles, _left_state, _left_event);
      _left_event = EVENT_EMPTY;

      // RIGHT
      if(_right_event == EVENT_EMPTY) {
        _right_event = _update_event(_right_ids, _right_poses, _right_angles, _right_state);
      }

      _right_state = _update_state(_right_ids, _right_poses, _right_angles, _right_state, _right_event);
      _right_event = EVENT_EMPTY;
    }
  }

  return NULL;
}
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

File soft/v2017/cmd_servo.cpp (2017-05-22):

#include "servo.hpp"

#include "feetech.h"
#include "shell.h"
#include "shell_commands.h"
#include "uart_stdio.h"

#include <stdio.h>
#include <string.h>

#define ARRAY_LEN(array) (sizeof(array)/sizeof(array[0]))

typedef struct {
    const char *name;
    int addr;
} reg_name_addr_t;

static const reg_name_addr_t regs8[] = {
    { "ID", SCS15_ID },
    { "BAUD_RATE", SCS15_BAUD_RATE },
    { "RETURN_DELAY_TIME", SCS15_RETURN_DELAY_TIME },
    { "RETURN_LEVEL", SCS15_RETURN_LEVEL },
    { "LIMIT_TEMPERATURE", SCS15_LIMIT_TEMPERATURE },
    { "MAX_LIMIT_VOLTAGE", SCS15_MAX_LIMIT_VOLTAGE },
    { "MIN_LIMIT_VOLTAGE", SCS15_MIN_LIMIT_VOLTAGE },
    { "ALARM_LED", SCS15_ALARM_LED },
    { "ALARM_SHUTDOWN", SCS15_ALARM_SHUTDOWN },
    { "COMPLIANCE_P", SCS15_COMPLIANCE_P },
    { "COMPLIANCE_D", SCS15_COMPLIANCE_D },
    { "COMPLIANCE_I", SCS15_COMPLIANCE_I },
    { "CW_DEAD", SCS15_CW_DEAD },
    { "CCW_DEAD", SCS15_CCW_DEAD },
    { "TORQUE_ENABLE", SCS15_TORQUE_ENABLE },
    { "LED", SCS15_LED },
    { "LOCK", SCS15_LOCK },
    { "PRESENT_VOLTAGE", SCS15_PRESENT_VOLTAGE },
    { "PRESENT_TEMPERATURE", SCS15_PRESENT_TEMPERATURE },
    { "REGISTERED_INSTRUCTION", SCS15_REGISTERED_INSTRUCTION },
    { "ERROR", SCS15_ERROR },
    { "MOVING", SCS15_MOVING },
};

static const reg_name_addr_t regs16[] = {
    { "MODEL_NUMBER", SCS15_MODEL_NUMBER },
    { "VERSION", SCS15_VERSION },
    { "MIN_ANGLE_LIMIT", SCS15_MIN_ANGLE_LIMIT },
    { "MAX_ANGLE_LIMIT", SCS15_MAX_ANGLE_LIMIT },
    { "MAX_TORQUE", SCS15_MAX_TORQUE },
    { "PUNCH", SCS15_PUNCH },
    { "IMAX", SCS15_IMAX },
    { "OFFSET", SCS15_OFFSET },
    { "GOAL_POSITION", SCS15_GOAL_POSITION },
    { "GOAL_TIME", SCS15_GOAL_TIME },
    { "GOAL_SPEED", SCS15_GOAL_SPEED },
    { "PRESENT_POSITION", SCS15_PRESENT_POSITION },
    { "PRESENT_SPEED", SCS15_PRESENT_SPEED },
    { "PRESENT_LOAD", SCS15_PRESENT_LOAD },
    { "VIR_POSITION", SCS15_VIR_POSITION },
    { "CURRENT", SCS15_CURRENT },
};

static const int32_t baudrates[] = {
    1000000L,
    500000L,
    250000L,
    128000L,
    115200L,
    76800L,
    57600L,
    38400L,
};

static int parse_dev(char *arg)
{
    int dev = atoi(arg);
    if (dev < 0 || 254 < dev) {
        printf("Error: Invalid device id (%s)\n", arg);
        return -1;
    }
    return dev;
}

static void parse_reg(char *arg, int *reg8, int *reg16)
{
    *reg8 = -1;
    *reg16 = -1;

    for (size_t i = 0 ; i < ARRAY_LEN(regs8) ; i++) {
        if (strcmp(arg, regs8[i].name) == 0) {
            *reg8 = regs8[i].addr;
            return;
        }
    }

    for (size_t i = 0 ; i < ARRAY_LEN(regs16) ; i++) {
        if (strcmp(arg, regs16[i].name) == 0) {
            *reg16 = regs16[i].addr;
            return;
        }
    }

    printf("Error: Invalid register (%s)\n", arg);
}

void print_registers(void) {
    puts("available 8bits registers :");
    for (size_t i = 0 ; i < ARRAY_LEN(regs8) ; i++) {
        printf("\t%s\n", regs8[i].name);
    }

    puts("available 16bits registers :");
    for (size_t i = 0 ; i < ARRAY_LEN(regs16) ; i++) {
        printf("\t%s\n", regs16[i].name);
    }
}

static int cmd_ping(int argc, char **argv) {
    int id = -1;

    if (argc != 2) {
        printf("usage; %s <dev_id>\n", argv[0]);
        return 1;
    }
    /* parse parameters */
    id = parse_dev(argv[1]);
    if (id < 0) {
        return -1;
    }

    /* ping */
    if (feetech_ping(&ServoBus::instance().stream(), id) == FEETECH_OK) {
        printf("Device %i responded\n", id);
    }
    else {
        printf("No response from %i\n", id);
    }
    return 0;
}

static int cmd_scan(int argc, char **argv) {
    int min = -1;
    int max = -1;

    if (argc == 3) {
        min = atoi(argv[1]);
        max = atoi(argv[2]);
        if (min < 0) {
            return -1;
        }
        if (max > 254) {
            return -1;
        }
        if (max < min) {
            return -1;
        }
    }
    else if (argc == 1) {
        min = 0;
        max = 254;
    }
    else {
        printf("usage; %s [<min_id> <max_id>]\n", argv[0]);
        return 1;
    }

    /* ping */
    puts("Scanning...");
    for (int id = min ; id < max ; id++) {
        if (feetech_ping(&ServoBus::instance().stream(), id) == FEETECH_OK) {
            printf("Device %i available\n", id);
        }
    }
    puts("End");
    return 0;
}

static int cmd_read(int argc, char **argv) {
    int id = -1;
    int reg8 = -1;
    int reg16 = -1;

    if (argc != 3) {
        printf("usage; %s <dev_id> <reg>\n", argv[0]);
        print_registers();
        return 1;
    }
    /* parse parameters */
    id = parse_dev(argv[1]);
    if (id < 0) {
        return -1;
    }

    parse_reg(argv[2], &reg8, &reg16);
    if (reg8 < 0 && reg16 < 0) {
        return -1;
    }

    /* read */
    feetech_t dev;
    feetech_init(&dev, &ServoBus::instance().stream(), id);
    if (reg8 >= 0) {
        uint8_t val = 0;
        int ret = feetech_read8(&dev, reg8, &val);
        if (ret != FEETECH_OK) {
            printf("Error[%i] : No response from %i\n", ret, id);
            return -1;
        }
        printf("%i\n", (int)val);
    }
    else {
        uint16_t val = 0;
        int ret = feetech_read16(&dev, reg16, &val);
        if (ret != FEETECH_OK) {
            printf("Error[%i] : No response from %i\n", ret, id);
            return -1;
        }
        printf("%i\n", (int)val);
    }
    return 0;
}

static int cmd_write(int argc, char **argv) {
    int id = -1;
    int reg8 = -1;
    int reg16 = -1;

    if (argc != 4) {
        printf("usage; %s <dev_id> <reg> <value>\n", argv[0]);
        print_registers();
        return 1;
    }
    /* parse parameters */
    id = parse_dev(argv[1]);
    if (id < 0) {
        return -1;
    }

    parse_reg(argv[2], &reg8, &reg16);
    if (reg8 < 0 && reg16 < 0) {
        return -1;
    }

    int val = atoi(argv[3]);
    if (val < 0) {
        return -1;
    }

    /* read */
    feetech_t dev;
    feetech_init(&dev, &ServoBus::instance().stream(), id);
    if (reg8 >= 0) {
        int ret = feetech_write8(&dev, reg8, val);
        if (ret != FEETECH_OK) {
            printf("Error[%i] : No response from %i\n", ret, id);
            return -1;
        }
        printf("Written %i at address %i\n", (int)val, reg8);
    }
    else {
        int ret = feetech_write16(&dev, reg16, val);
        if (ret != FEETECH_OK) {
            printf("Error[%i] : No response from %i\n", ret, id);
            return -1;
        }
        printf("Written %i at address %i\n", (int)val, reg16);
    }
    return 0;
}
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

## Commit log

2015-05-13 Added STM32Cube and aversive--
2015-06-22 Moved sources. Added missing gp2 drivers.
    [main.cpp]
2015-06-22 Added 2015 meca
    [axe.ipt, axe_roue_moteur.ipt, base.ipt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]
2015-06-22 Renamed encoder because of wrong vendor name
2015-07-19 Begin meca v2016.
    [base.ipt, encoder.iam, encoder_block.iam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]
2015-08-03 Added new poulie (conrad)
    [wheel.iam]
2015-08-03 Added vis
    [base.ipt, robot_base.iam, wheel_block.iam]
2015-08-03 (meca) Added patin
    [base.ipt, robot_base.iam]
2015-08-03 (meca) Added motors.
    [motor.iam, robot_base.iam, upper_base.ipt]
2015-08-03 Added batteries.
    [base.ipt, battery_base.ipt, odometer_base.ipt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]
2015-08-04 (meca) Test batteries.
    [odometer_block.iam, robot_base.iam]
2015-08-04 (meca) New batteries tests.
    [robot_base.iam, upper_base.ipt]
2015-08-27 Wheel base improvement.
    [robot_base.iam, wheel_base.ipt, wheel_base_asm.iam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]
2015-09-12 Added tendeur.
    [robot_base.iam, tendeur.ipt, tendeur_base.ipt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]
2015-09-15 Improved tendeur
    [tendeur_base_low.ipt, tendeur_base_up.ipt]
2015-09-15 Improved Odometer Base
    [odometer_base.ipt]
2015-09-23 Adding schematic of the rolling base board
    [Com.sch, Driver.sch, Encoder.sch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]
2015-09-25 Adding footprints for the rolling base board
2015-09-26 Adding missing power connector footprint
2015-09-26 Updated the schematics to use the proper footprints.
    Also regenerated the net list file.
    [Com.sch, Driver.sch, Encoder.sch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]
2015-09-28 Starting rolling base board's routing
    [RollingBaseBoard.kicad_pcb]
2015-09-29 Progressing on rolling base board's routing
    [RollingBaseBoard.kicad_pcb]
2015-09-30 Replacing M4 screws with M3 ones
    [RollingBaseBoard.kicad_pcb]
2015-10-06 Progressing on the rolling base board
    [RollingBaseBoard.kicad_pcb]
2015-10-07 Improving a few footprints
2015-10-08 Completing rolling base board, only a few minor fixes are left to do
    [RollingBaseBoard.kicad_pcb]
2015-10-11 Fixing rolling base board routing's right angles
    [RollingBaseBoard.kicad_pcb]
2015-10-11 Adding all the missing refs on rolling base board routing
    [RollingBaseBoard.kicad_pcb]
2015-10-11 Minor fix to rolling base board routing
    [RollingBaseBoard.kicad_pcb]
2015-10-11 Finished tendeur
    [encoder_support.ipt, odometer_block.iam, robot_base.iam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]
2015-10-13 Updated rolling base board CMS footprints to actually have room to solder them
2015-10-17 Added bumpers and gp2 sensors
2015-10-17 Finished rolling base
    [base.ipt, encoder.iam, encoder_block.iam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]
2015-10-25 Fixing rolling base board routing after footprints change.
    [RollingBaseBoard.kicad_pcb]
2015-10-25 Optimising rolling base board routing a bit
    Reduced via count by 6
    [RollingBaseBoard.kicad_pcb]
2015-10-28 Optimising rolling base board routing some more. Also removing a GND loop.
    [RollingBaseBoard.kicad_pcb]
2015-10-28 The rolling base board now has a name. Please welcome Hermes in the family.
    [RollingBaseBoard.kicad_pcb]
2015-11-17 Fixing Hermes footprints and routing, bumped to v2.
    [RollingBaseBoard.kicad_pcb]
2015-11-18 Final checks and fixes to Hermes v2
    It's now ready for production.
    [RollingBaseBoard.kicad_pcb]
2015-11-19 Moving elec/RollingBaseBoard to elec/Hermes
    [Com.sch, Driver.sch, Encoder.sch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]
2017-04-04 improved motors pwm command
2017-04-17 added feetech dynamixel, debug gyro and xtimer collision
    [main.c]
2017-04-17 arm state test
2017-04-27 added second arm
2017-05-02 added v2017 board schematics
    [Com.sch, Driver.sch, Embedded.sch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]
2017-05-02 begining clean arm.c
2017-05-03 Arm state machine working
2017-05-03 Updated v2017 schematics and added its Components.md
    [Com.sch, Driver.sch, Embedded.sch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]
2017-05-11 added boards dir to copy specific board implementation
2017-05-11 fix files that were not moved
    [arm.c]
2017-05-18 added Action and CalibrateAction (not tested)
2017-05-21 added gyro config
2017-05-21 new arm retracted pose
2017-05-21 new arm retracted pose (fix)
    [arm.cpp]
2017-05-21 added robot config + first attempt to calibrate robot
2017-05-21 new robot calibration + debug negative speed
2017-05-22 added funny + servobus
2017-05-22 arm disabled at init
2017-05-30 servo retracted pose
2017-05-30 grip max torque
2017-05-30 add arm cmd
2017-05-30 implement arm set angle
